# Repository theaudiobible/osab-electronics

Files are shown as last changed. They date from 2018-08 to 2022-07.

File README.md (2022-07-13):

## OSAB - the Open Source Audio Bible player
## [theaudiobible.org](http://theaudiobible.org/)
#### Copyright (C) 2011-2022 Theophilus

OSAB is a design for a portable audio Bible player released under the MIT Licence in the hope that it will be used by others worldwide to produce and distribute portable audio players that are specifically designed to share God's word with those who need to hear.

The intention is to share firmware, software, schematics, PCB layout and enclosure design along with instructions on how to put it all together.  The intention with the enclosure is that it be 3D-printable on a low cost FDM 3D printer, or mass-producible via injection moulding.

## osab-electronics
This is the repository for the EDA files for OSAB.

### Dependencies
- The schematic and PCB design tool is [KiCad](http://kicad.org/)
- [meshconv](https://www.patrickmin.com/meshconv/) is used to convert the VRML file to STL for use in OpenSCAD for the enclosure design.

### Generate STL file
To generate `osab.stl` for inclusion in the `osab-enclosure/osab.stl` soft link:
1. Open `osab.kicad_pcb` in KiCad Pcbnew.
2. Click `File` > `Export` > `VRML`.
3. Set these options:
   - `Coordinate origin options`: `User defined origin`
   - `User defined origin`:
      - `Units`: `mm`
      - `X`: `150`
      - `Y`: `100`
   - `VRML Units for Output Files`: `mm`
4. Click `OK`.  The output file should be `osab.wrl`.
5. Quit Pcbnew.
6. Download `meshconv` from https://www.patrickmin.com/meshconv/
7. Put meshconv somewhere in your PATH:
   `sudo chown root.root meshconv`
   `sudo chmod 755 meshconv`
   `sudo mv meshconv /usr/local/bin`
8. Convert the VRML file to STL as follows:
   `meshconv osab.wrl -c stl`
9. The output file `osab.stl` should be in the `osab-electronics` directory - there is a soft link from `osab-enclosure/osab.stl` to this file for inclusion in `osab-enclosure/osab-enclosure.scad`.

### Licence
This is open source hardware released under the MIT Licence - please see the LICENCE file in this directory.

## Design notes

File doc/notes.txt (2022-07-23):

Clone osab-electronics git repo
===============================

export OSAB_DIR=~/dev/osab
if [[ ! -d ${OSAB_DIR} ]]; then
  mkdir -p ${OSAB_DIR}
fi
cd ${OSAB_DIR}
if [[ ! -d osab-electronics ]]; then
  git clone https://github.com/audiobibleplayer/osab-electronics
fi
cd osab-electronics
git pull

External symbol + footprint + 3D libraries
==========================================

VS1000
------
library/vs10xx.lib is from http://www.kicadlib.org/modules/vs10xx.lib.zip

curl -o ${OSAB_DIR}/osab-electronics/libraries/symbols/vs10xx.lib https://raw.githubusercontent.com/karawin/Ka-Radio/master/Hardware/KiCAD/Main/vs10xx.lib

TF-01A
------
Download LIB_TF-01A.zip from https://componentsearchengine.com/ga/model.php?partID=2371673
unzip LIB_TF-01A.zip
cp -av TF-01A/3D/* ${OSAB_DIR}/osab-electronics/3D/
cp -av TF-01A/KiCad/TF01A.kicad_mod ${OSAB_DIR}/osab-electronics/libraries/footprints/samacsys.pretty/
cp -av TF-01A/KiCad/TF-01A.lib ${OSAB_DIR}/osab-electronics/libraries/symbols/

TYPE-C-31-M-12
--------------
curl -o ${OSAB_DIR}/osab-electronics/3D/TYPE-C-31-M-12.step https://raw.githubusercontent.com/ai03-2725/Type-C.pretty/master/HRO%20%20TYPE-C-31-M-12.step

XKB5858-Z-F
-----------
Download the STEP AP242 model from https://traceparts.com/ and place xkb5858-z-f.stp in ${OSAB_DIR}/osab-electronics/3D/

Kicad 5 setup in Linux
======================

Initial Setup
-------------

If upgrading from Kicad v4, assuming that you do not want to use v4 any more, then backup and remove ~/.config/kicad.

Clone official KiCad libraries into ~/dev/kicad.libs/OfficialKiCadLibrary from:
https://github.com/KiCad/kicad-symbols
https://github.com/KiCad/kicad-footprints
https://github.com/KiCad/kicad-packages3d

Run KiCad 5 and change the default global libraries to point to these closed official libraries.  Go to:
Preferences > Configure Paths
and set as follows (substitute 'user' for your user ID):

KICAD_SYMBOL_DIR   /home/user/dev/kicad.libs/OfficialKiCadLibrary/kicad-symbols
KICAD_TEMPLATE_DIR /home/user/dev/kicad.libs/OfficialKiCadLibrary/kicad-templates
KISYS3DMOD         /home/user/dev/kicad.libs/OfficialKiCadLibrary/kicad-packages3d
KISYSMOD           /home/user/dev/kicad.libs/OfficialKiCadLibrary/kicad-footprints

Create a dummy project so that you can set up the library tables for symbols and footprints - sym-lib-table and fp-lib-table:
File > New > Project
(select a temp path and file name)

Open the Schematic layout editor. A dialog titled 'Configure Global Symbol Library Table' will pop up.  Select the default:
Copy default global symbol library table (recommended)
and click OK.  This will create the file:
~/.config/kicad/sym-lib-table

Close Eeschema.

Open the PCB layout editor (Pcbnew). A dialog will pop up saying that you have run Pcbnew for the first time - click OK.  The Footprint library table should now exist at:
~/.config/kicad/fp-lib-table

Another dialog will pop up offering to enable graphics acceleration - it's generally best to enable this.

Close Pcbnew.

OSAB-specific setup
-------------------

Open the OSAB project in KiCad:
File > Open Project
Browse to osab/osab-electronics and open osab.pro.

Open osab.sch.

In Eeschema, go to:
Preferences > Manage Symbol Libraries...
Select the 'Project Specific Libraries' tab.
Click 'Add existing library to table' and browse to osab/osab-electronics/libraries/symbols and select osab.lib
Click 'Add existing library to table' and browse to osab/osab-electronics/libraries/symbols and select vs10xx.lib
Click 'Add existing library to table' and browse to osab/osab-electronics/libraries/symbols and select TF-01A.lib
Click OK to close the Symbol Libraries page.

In Footprint Editor, go to:
Preferences > Manage Footprint Libraries...
Select the 'Project Specific Libraries' tab.
Click 'Add existing library to table' and browse to osab/osab-electronics/libraries/footprints and select osab.pretty
 - for 'Description', add "OSAB footprint library"
Click 'Add existing library to table' and browse to osab/osab-electronics/libraries/footprints and select samacsys.pretty
 - for 'Description', add "SamacSys footprint library"
Click OK to close the Footprint Libraries page.

In Footprint Editor, go to:
Preferences > Configure Paths...
Under '3D Search Paths', click + and enter the following details:
Alias: KIPRJ3DMOD
Path: /home/user/dev/osab/osab-electronics/3D  (substitute 'user' appropriately)
Description: Project-specific 3D models
Click OK to close the Configure Paths page.

In Footprint Editor, go to:
Navigate to samacsys > TF01A
Double-click TF01A
Click Footprint properties
Select 3D Settings tab
Delete the existing 3D Model (click trash-can icon)
Click the + icon and add the following: ${KIPRJMOD}/3D/TF-01A.stp
Click OK

Save changes

Customising Footprints
======================
Change pin widths of TCS7191 from 0.5 mm to 0.4 mm to pass DRC.
Move X coordinate of pin MP1 of TF-01A from -7.34 mm to -7.44 mm to pass DRC.

Board Setup
===========
In Pcbnew, go to File > Board Setup... > Design Rules:
Allow blind/buried vias: uncheck
Allow micro vias (uVias) : uncheck
Require courtyard definitions in footprints: uncheck
Prohibit overlapping courtyards: check
Minimum track width: 0.2 mm
Minimum via diameter: 0.4 mm
Minimum via drill: 0.3 mm
Minimum uVia diameter: 0.2 mm
Minimum uVia drill: 0.1 mm
Minimum hole to hole: 0.25 mm

Design Rules > Net Classes:
Name    Clearance   Track Width   Via Size  Via Drill   uVia Size   uVia Drill  dPair Width   dPair Gap
Default 0.2 mm      0.25 mm       0.8 mm    0.4 mm      0.3 mm      0.1 mm      0.2 mm        0.25 mm
Power   0.2 mm      0.40 mm       0.8 mm    0.4 mm      0.3 mm      0.1 mm      0.2 mm        0.25 mm

Net Class Memberships (other than Default)
Net       Net Class
AVDD      Power
GND       Power
GNDA      Power
VCC       Power
VDD       Power

Howtos
======
To add new symbol fields: Preferences > Preferences > Eeschema > Field Name Templates > +

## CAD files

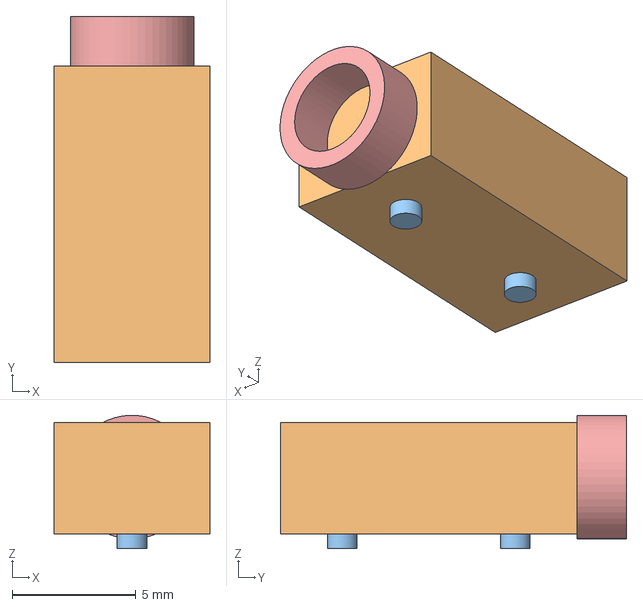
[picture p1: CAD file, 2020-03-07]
3D/PJ-3420.step
6.30 x 14.0 x 5.40 mm

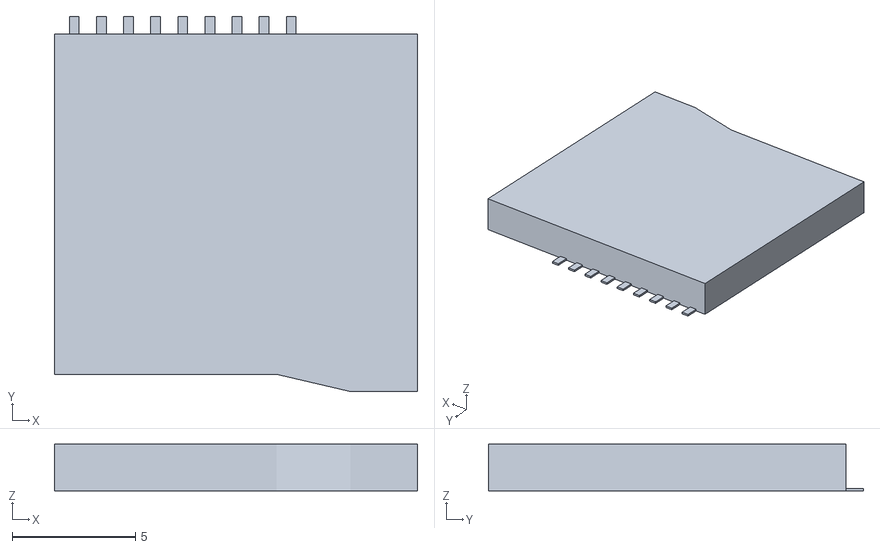
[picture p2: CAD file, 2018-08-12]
3D/Memory_Card_microSD_KNF1110X-AXX082.stl
14.7 x 15.2 x 1.90

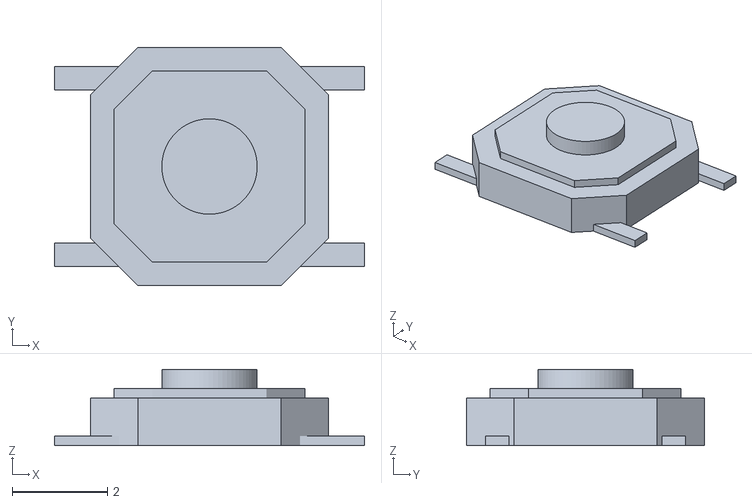
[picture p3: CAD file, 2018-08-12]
3D/pushbutton_5x5H1.stl
6.50 x 5.00 x 1.60

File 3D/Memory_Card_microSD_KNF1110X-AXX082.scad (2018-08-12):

/*
 * Memory_Card_microSD_KNF1110X-AXX082.scad - 3D component for Kicad
 * 
 * Copyright (C) 2014 Theophilus
 *
 * osab
 *
 * License: Matthew 10:8b - "freely ye have received, freely give."
 *
 * Use this information at your own risk.
 *
 */

// begin pin

// end pin
module pin() {
	cube([0.4,0.71,0.1]);
}

linear_extrude(height = 1.9)
polygon(points = [[0,0], [0,13.80], [14.72,13.80], [14.72,-0.7], [12.00,-0.7], [9.00,0.00]]);

start = 0.6;
translate([start,13.80,0]) pin();
translate([start+1*1.1,13.80,0]) pin();
translate([start+2*1.1,13.80,0]) pin();
translate([start+3*1.1,13.80,0]) pin();
translate([start+4*1.1,13.80,0]) pin();
translate([start+5*1.1,13.80,0]) pin();
translate([start+6*1.1,13.80,0]) pin();
translate([start+7*1.1,13.80,0]) pin();
translate([start+8*1.1,13.80,0]) pin();

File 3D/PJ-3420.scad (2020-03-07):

/*
 * PJ-3420.scad - Stereo 3.5mm audio socket
 * 
 * Copyright (C) 2015-2020 Theophilus
 *
 * osab
 *
 * License: Matthew 10:8b - "freely ye have received, freely give."
 *
 * Use this information at your own risk.
 *
 */

$fa=0.1; // default minimum facet angle is now 0.1
$fs=0.1; // default minimum facet size is now 0.1 mm

cube([6.3,12,4.5],center=true);
translate([0,7,0.05]) rotate([90,0,0]) difference() {
	cylinder(h=2,d=5,center=true);
	cylinder(h=2.1,d=3.6,center=true);
}

translate([0,3.5,-2.55]) cylinder(h=0.6,d=1.2,center=true);
translate([0,-3.5,-2.55]) cylinder(h=0.6,d=1.2,center=true);

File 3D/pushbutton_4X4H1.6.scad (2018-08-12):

/*
 * 4x4H1.6.scad - 3D Pushbutton Switch for Kicad
 * 
 * Copyright (C) 2015 Theophilus
 *
 * osab
 *
 * License: Matthew 10:8b - "freely ye have received, freely give."
 *
 * Use this information at your own risk.
 *
 */

$fa=0.1; // default minimum facet angle is now 0.1
$fs=0.1; // default minimum facet size is now 0.1 mm

module pin() {
	cube([1.5,0.5,0.2]);
}

linear_extrude(height=1)
polygon([[0,1],[1,0],[4,0],[5,1],[5,4],[4,5],[1,5],[0,4]]);

translate([0.5,0.5,1])
linear_extrude(height=0.2)
polygon([[0,4/5*1],[4/5*1,0],[4/5*4,0],[4/5*5,4/5*1],[4/5*5,4/5*4],[4/5*4,4/5*5],[4/5*1,4/5*5],[0,4/5*4]]);

translate([2.5,2.5,1.2])
cylinder(h=0.4, d=2);

translate([-0.75,0.4,0])
pin();

translate([-0.75,4.1,0])
pin();

translate([4.25,0.4,0])
pin();

translate([4.25,4.1,0])
pin();

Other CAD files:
3D/PJ3106.scad
3D/pushbutton_5x5H1.6.scad

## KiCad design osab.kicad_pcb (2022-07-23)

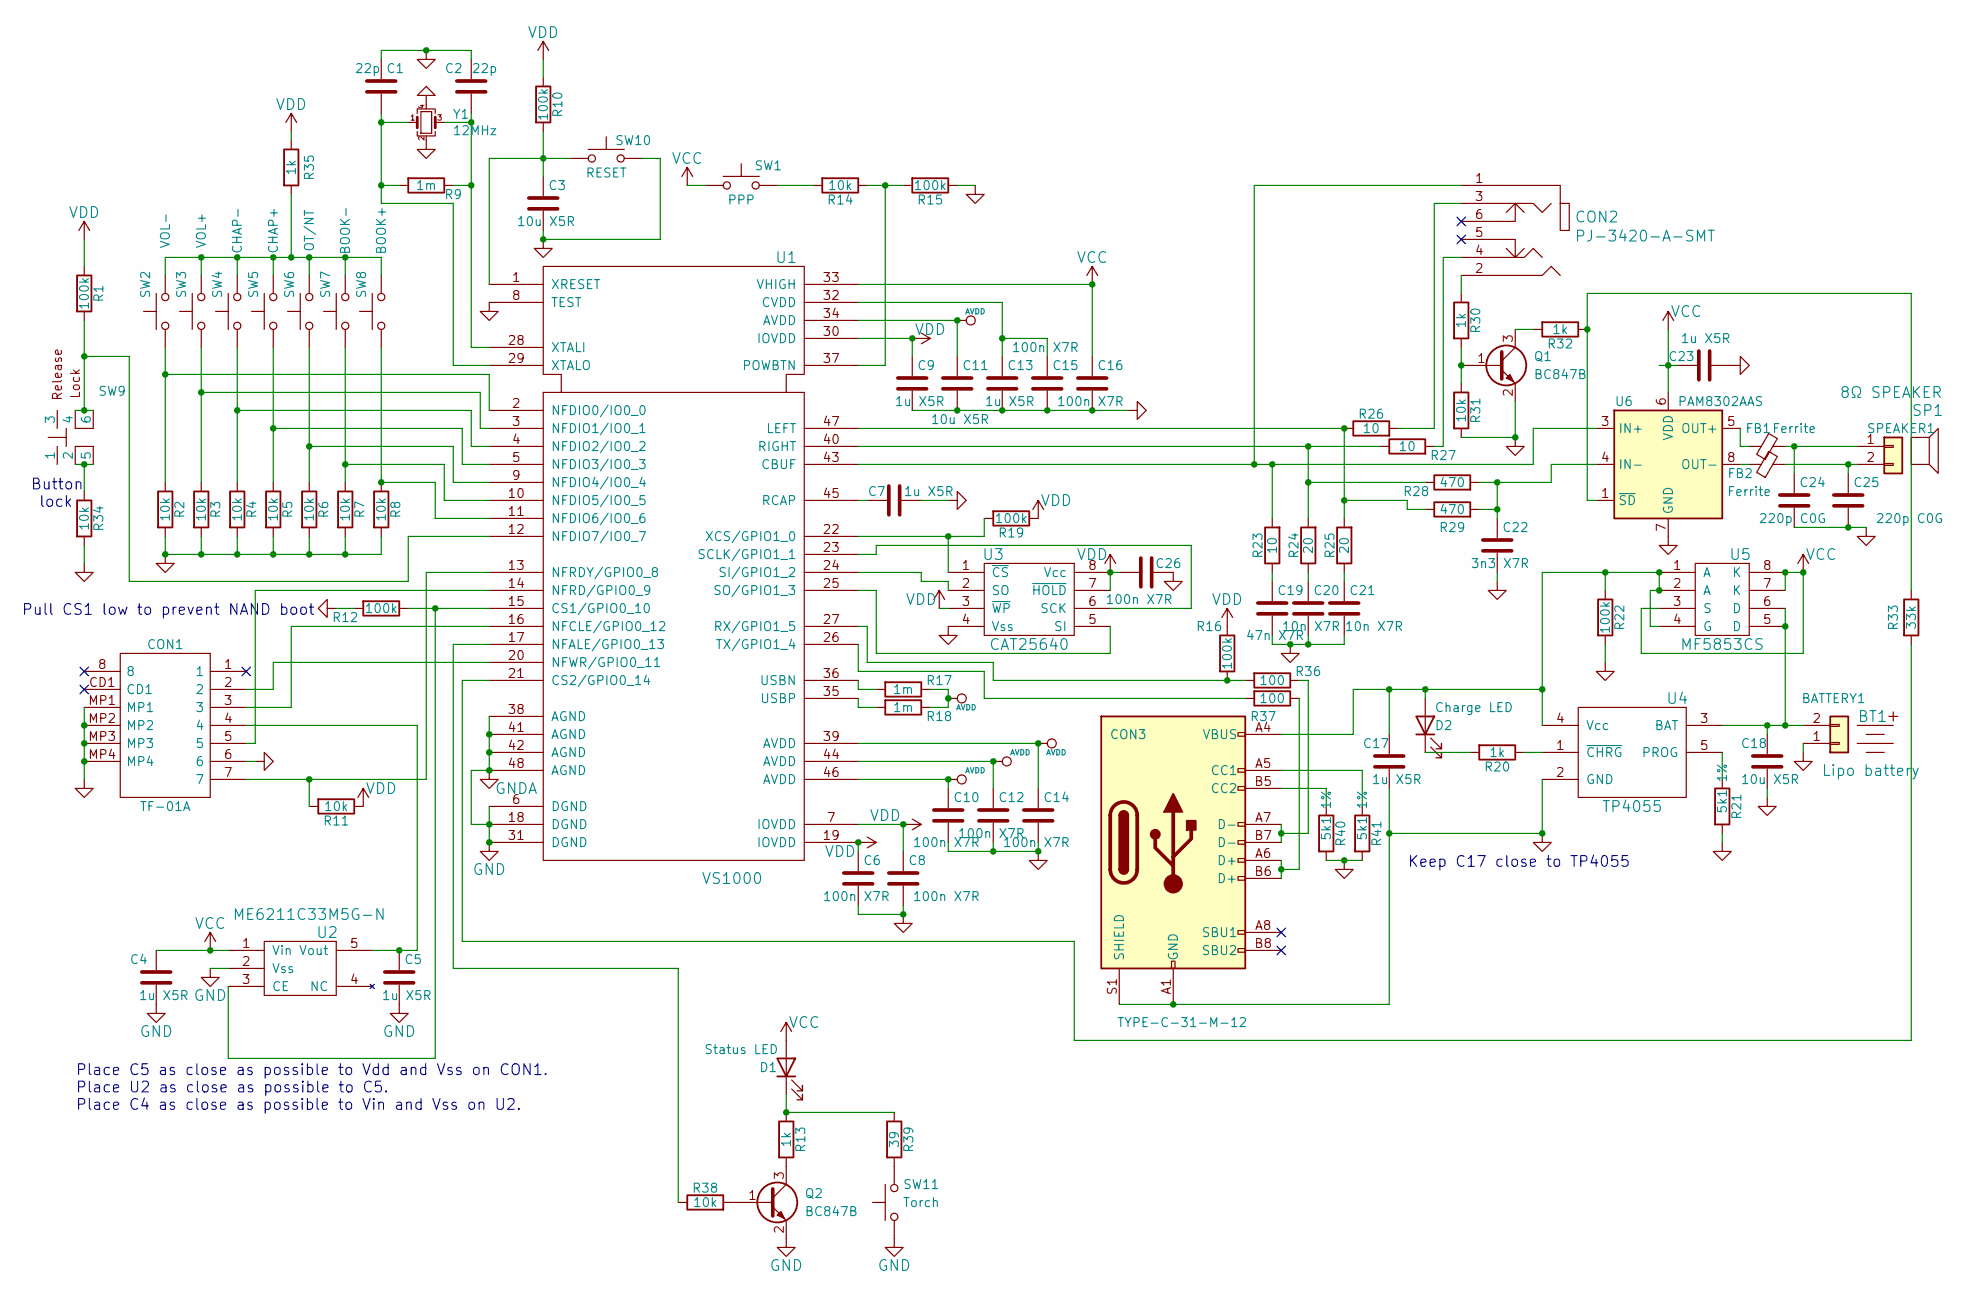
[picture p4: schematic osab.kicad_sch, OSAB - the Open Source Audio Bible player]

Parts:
BATTERY1: Conn_01x02; JST_PH_S2B-PH-SM4-TB_1x02-1MP_P2.00mm_Horizontal; MPN KH-A2001WF-02A; LCSC C2688784
BT1: Lipo battery; NULL; MPN BZ 602030
C1, C2: 22p; C_0603_1608Metric; MPN CL10C220JB8NNNC; LCSC C1653
C3, C11, C18: 10u X5R; C_0603_1608Metric; MPN CL10A106KP8NNNC; LCSC C19702
C4, C5, C7, C9, C13, C17, C23: 1u X5R; C_0603_1608Metric; MPN CL10A105KB8NNNC; LCSC C15849
C6, C8, C10, C12, C14, C15, C16, C26: 100n X7R; C_0603_1608Metric; MPN CL10B104KB8NNNC; LCSC C1591
C19: 47n X7R; C_0603_1608Metric; MPN CL10B473KB8NNNC; LCSC C1622
C20, C21: 10n X7R; C_0603_1608Metric; MPN CL10B103KB8NNNC; LCSC C1589
C22: 3n3 X7R; C_0603_1608Metric; MPN CL10B332KB8NNNC; LCSC C1613
C24, C25: 220p C0G; C_0603_1608Metric; MPN CL10C221JB8NNNC; LCSC C27675
CON1: TF-01A; TF01A; Manufacturer_Part_Number TF-01A; LCSC C91145
CON2: PJ-3420-A-SMT; MPN PJ-3420-A-SMT; LCSC C319102
CON3: TYPE-C-31-M-12; USB_C_Receptacle_HRO_TYPE-C-31-M-12; MPN TYPE-C-31-M-12; LCSC C165948
D1: Status LED; 0805-LED; MPN MHS171WDT-C2; LCSC C693902
D2: Charge LED; 0602-LED; MPN LTST-S270KRKT; LCSC C125114
FB1, FB2: Ferrite; R_0603_1608Metric; MPN MMZ1608Y152BTA00; LCSC C275454
Q1, Q2: BC847B; SOT-23; MPN BC847BLT1G; LCSC C94393
R1, R10, R12, R15, R16, R19, R22: 100k; R_0603_1608Metric; MPN ARG03FTC1003; LCSC C217682
R2, R3, R4, R5, R6, R7, R8, R11, R14, R31, R34, R38: 10k; R_0603_1608Metric; MPN ARG03FTC1002; LCSC C217687
R9, R17, R18: 1m; R_0603_1608Metric; MPN AR03FTC1004; LCSC C234360
R13, R20, R30, R32, R35: 1k; R_0603_1608Metric; MPN ARG03FTC1001; LCSC C217840
R21, R40, R41: 5k1 1%; R_0603_1608Metric; MPN ARG03FTC5101; LCSC C218090
R23, R26, R27: 10; R_0603_1608Metric; MPN ARG03FTC0100; LCSC C217691
R24, R25: 20; R_0603_1608Metric; MPN ARG03FTC0200; LCSC C217873
R28, R29: 470; R_0603_1608Metric; MPN ARG03FTC4700; LCSC C218042
R33: 33k; R_0603_1608Metric; MPN ARG03FTC3302; LCSC C217971
R36, R37: 100; R_0603_1608Metric; MPN ARG03FTC1000; LCSC C217683
R39: 39; R_0603_1608Metric; MPN 0603WAF390JT5E; LCSC C23154
SP1: 8Ω SPEAKER; NULL; MPN 28M03-8T-H52-L70; LCSC C391017
SPEAKER1: Conn_01x02; WAFER-125W-2P; MPN WAFER-125W-2P; LCSC C2840410
SW1: PPP; SW_SPST_TL3342; MPN K2-1187SQ-A4SW-06; LCSC C92584
SW2: VOL-; SW_SPST_TL3342; MPN K2-1187SQ-A4SW-06; LCSC C92584
SW3: VOL+; SW_SPST_TL3342; MPN K2-1187SQ-A4SW-06; LCSC C92584
SW4: CHAP-; SW_SPST_TL3342; MPN K2-1187SQ-A4SW-06; LCSC C92584
SW5: CHAP+; SW_SPST_TL3342; MPN K2-1187SQ-A4SW-06; LCSC C92584
SW6: OT/NT; SW_SPST_TL3342; MPN K2-1187SQ-A4SW-06; LCSC C92584
SW7: BOOK-; SW_SPST_TL3342; MPN K2-1187SQ-A4SW-06; LCSC C92584
SW8: BOOK+; SW_SPST_TL3342; MPN K2-1187SQ-A4SW-06; LCSC C92584
SW9: XKB5858-Z-F; MPN XKB5858-Z-F; LCSC C780036
SW10: RESET; SW_SPST_TL3342; MPN K2-1187SQ-A4SW-06; LCSC C92584
SW11: Torch; SW_SPST_TL3342; MPN K2-1187SQ-A4SW-06; LCSC C92584
U1: VS1000; LQFP-48_7x7mm_P0.5mm; MPN VS1000D-L; LCSC C486305
U2: ME6211C33M5G-N; SOT-23-5; MPN ME6211C33M5G-N; LCSC C82942
U3: CAT25640; SOIC-8_3.9x4.9mm_P1.27mm; MPN CAT25640VI-GT3; LCSC C153776
U4: TP4055; SOT-23-5; MPN TP4055; LCSC C28441
U5: MF5853CS; DFN8-2x3-0.65pitch; MPN MF5853CS; LCSC C375698
U6: PAM8302AAS; MSOP-8_3x3mm_P0.65mm; MPN PAM8302AASCR; LCSC C113367
Y1: 12MHz; Crystal_SMD_3225-4Pin_3.2x2.5mm; MPN X322512MSB4SI; LCSC C9002

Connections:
AVDD: C10.1, C11.1, C12.1, C14.1, R17.1, R18.1, U1.34 (AVDD), U1.39 (AVDD), U1.44 (AVDD), U1.46 (AVDD)
GND: BATTERY1.1, C1.1, C2.1, C3.2, C4.2, C5.2, C6.2, C7.1, C8.2, C9.2, C10.2, C11.2, C12.2, C13.2, C14.2, C15.2, C16.2, C17.2, C18.2, C19.2, C20.2, C21.2, C22.2, C23.2, C24.2, C25.2, C26.2, CON1.6, CON1.MP1, CON1.MP2, CON1.MP3, CON1.MP4, CON3.A1 (GND), CON3.A12 (GND), CON3.B1 (GND), CON3.B12 (GND), CON3.S1 (SHIELD), Q1.2 (E), Q2.2 (E), R2.2, R3.2, R4.2, R5.2, R6.2, R7.2, R8.2, R12.2, R15.1, R21.2, R22.2, R31.2, R34.2, R40.2, R41.2, SW10.1, SW11.1, U1.6 (DGND), U1.8 (TEST), U1.18 (DGND), U1.31 (DGND), U1.38 (AGND), U1.41 (AGND), U1.42 (AGND), U1.48 (AGND), U2.2 (Vss), U3.4 (Vss), U4.2 (GND), U6.7 (GND), Y1.2, Y1.4
unnamed: BATTERY1.2, C18.1, U4.3 (BAT), U5.5 (D), U5.6 (D)
unnamed: C1.2, R9.2, U1.29 (XTALO), Y1.1
unnamed: C2.2, R9.1, U1.28 (XTALI), Y1.3
unnamed: C3.1, R10.2, SW10.2, U1.1 (XRESET)
unnamed: C5.1, CON1.4, U2.5 (Vout)
unnamed: C7.2, U1.45 (RCAP)
unnamed: C13.1, C15.1, U1.32 (CVDD)
unnamed: C17.1, CON3.A4 (VBUS), CON3.A9 (VBUS), CON3.B4 (VBUS), CON3.B9 (VBUS), D2.2 (A), R22.1, U4.4 (Vcc), U5.1 (A), U5.2 (A), U5.4 (G)
unnamed: C19.1, R23.1
unnamed: C20.1, R24.1
unnamed: C21.1, R25.1
unnamed: C22.1, R28.2, R29.2, U6.4 (IN-)
unnamed: C24.1, FB1.2, SPEAKER1.1
unnamed: C25.1, FB2.2, SPEAKER1.2
unnamed: CON1.2, U1.20 (NFWR/GPIO0_11)
unnamed: CON1.3, U1.16 (NFCLE/GPIO0_12)
unnamed: CON1.5, U1.14 (NFRD/GPIO0_9)
unnamed: CON1.7, R11.2, U1.13 (NFRDY/GPIO0_8)
unnamed: CON2.1, R23.2, U1.43 (CBUF), U6.3 (IN+)
unnamed: CON2.2, R30.1
unnamed: CON2.3, R26.2
unnamed: CON2.4, R27.2
unnamed: CON3.A5 (CC1), R41.1
unnamed: CON3.A6 (D+), CON3.B6 (D+), R37.1
unnamed: CON3.A7 (D-), CON3.B7 (D-), R36.1
unnamed: CON3.B5 (CC2), R40.1
unnamed: D1.1 (K), R13.1, R39.1
unnamed: D2.1 (K), R20.2
unnamed: FB1.1, U6.5 (OUT+)
unnamed: FB2.1, U6.8 (OUT-)
unnamed: Q1.1 (B), R30.2, R31.1
unnamed: Q1.3 (C), R32.2
unnamed: Q2.1 (B), R38.2
unnamed: Q2.3 (C), R13.2
unnamed: R1.2, SW9.4, SW9.6, U1.12 (NFDIO7/IO0_7)
unnamed: R2.1, SW2.1, U1.2 (NFDIO0/IO0_0)
unnamed: R3.1, SW3.1, U1.3 (NFDIO1/IO0_1)
unnamed: R4.1, SW4.1, U1.4 (NFDIO2/IO0_2)
unnamed: R5.1, SW5.1, U1.5 (NFDIO3/IO0_3)
unnamed: R6.1, SW6.1, U1.9 (NFDIO4/IO0_4)
unnamed: R7.1, SW7.1, U1.10 (NFDIO5/IO0_5)
unnamed: R8.1, SW8.1, U1.11 (NFDIO6/IO0_6)
unnamed: R12.1, U1.15 (CS1/GPIO0_10), U2.3 (CE)
unnamed: R14.1, R15.2, U1.37 (POWBTN)
unnamed: R14.2, SW1.2
unnamed: R16.2, R36.2, U1.27 (RX/GPIO1_5)
unnamed: R17.2, U1.36 (USBN)
unnamed: R18.2, U1.35 (USBP)
unnamed: R19.2, U1.22 (XCS/GPIO1_0), U3.1 (~CS)
unnamed: R20.1, U4.1 (~CHRG)
unnamed: R21.1, U4.5 (PROG)
unnamed: R24.2, R27.1, R28.1, U1.40 (RIGHT)
unnamed: R25.2, R26.1, R29.1, U1.47 (LEFT)
unnamed: R32.1, R33.1, U6.1 (~SD)
unnamed: R33.2, U1.21 (CS2/GPIO0_14)
unnamed: R34.1, SW9.2, SW9.5
unnamed: R35.2, SW2.2, SW3.2, SW4.2, SW5.2, SW6.2, SW7.2, SW8.2
unnamed: R37.2, U1.26 (TX/GPIO1_4)
unnamed: R38.1, U1.17 (NFALE/GPIO0_13)
unnamed: R39.2, SW11.2
unnamed: U1.23 (SCLK/GPIO1_1), U3.6 (SCK)
unnamed: U1.24 (SI/GPIO1_2), U3.2 (SO)
unnamed: U1.25 (SO/GPIO1_3), U3.5 (SI)
VCC: C4.1, C16.1, C23.1, D1.2 (A), SW1.1, U1.33 (VHIGH), U2.1 (Vin), U5.3 (S), U5.7 (K), U5.8 (K), U6.6 (VDD)
VDD: C6.1, C8.1, C9.1, C26.1, R1.1, R10.1, R11.1, R16.1, R19.1, R35.1, U1.7 (IOVDD), U1.19 (IOVDD), U1.30 (IOVDD), U3.3 (~WP), U3.7 (~HOLD), U3.8 (Vcc)

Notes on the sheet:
Button lock
Pull CS1 low to prevent NAND boot
Place C5 as close as possible to Vdd and Vss on CON1. Place U2 as close as possible to C5. Place C4 as close as possible to Vin and Vss on U2.
Keep C17 close to TP4055

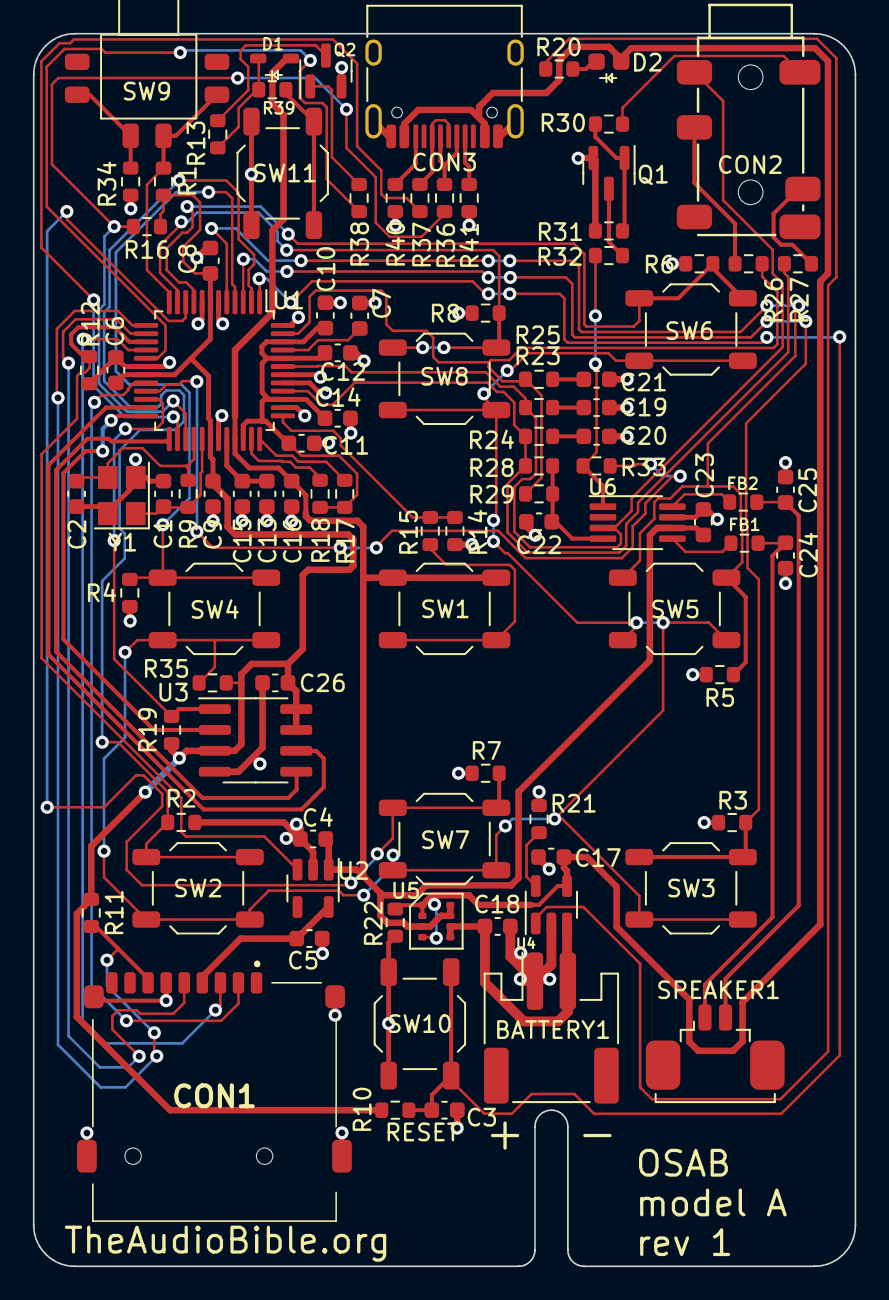
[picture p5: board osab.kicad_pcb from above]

Board: 2 copper layers, 50.0 x 75.0 mm, 98 parts (0 on the bottom side), 67 nets.

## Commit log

2018-08-12 Initial commit.
    [Memory_Card_microSD_KNF1110X-AXX082.scad, Memory_Card_microSD_KNF1110X-AXX082.stl, PJ3106.scad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]
2019-08-07 Changed all rescue symbols to their appropriate libraries
    Got rid of some superfluous? files
    Reorganised directory structure of libraries
    Kicad seems to have changed some refs
    Changed all X5R caps to X7R
    Updated board rev
    kicad-5: Changed footprints from 0603 to 0805 for hand soldering
    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
    [osab.sch]
2020-02-15 Comitting updates without zero ohm resistors to make a good point to branch multi-layer boards
    usb-c: Swapped microB for Korean-Hroparts TYPE-C-31-M-12
    usb-c: Multiple collapsed/consolidated changes
    usb-c: Added SamacSys model for TF-01A
    usb-c: A multitude of changes
    usb-c: Various changes
    usb-c: Various changes
    usb-c: Initial placement of all components on PCB
    usb-c: Extended board by 20mm
    usb-c: Further pcb layout changes
    usb-c: Changed headphone socket to PJ-3420-A-SMT
    usb-c: A multitude of changes
    usb-c: Rework around TF-01A
    usb-c: Working on pcb
    usb-c: Working on pcb
    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
    [osab.kicad_pcb, osab.sch, pushbutton_5x5H1.6.scad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]
2020-03-07 single-sided: Added 3D model for PJ-3420 3.5mm audio socket
    [PJ-3420.scad, PJ-3420.step, PJ3106.stl]
2020-08-02 Changed website in master branch
    [osab.sch]
2020-08-08 single-sided: Instructions to generate STL file for osab-enclosure
2021-11-08 Update README.md
    https://forum.kicad.info/t/warning-avoid-all-links-to-kicad-pcb-org-use-kicad-org/31521
2022-06-06 Production into master for OSAB model A rev 1 (#2)
    * production: C1,C2 -> 0603
    * production: C3,C11,C18 10u -> 0603
    * production: C4,C5,C7,C9,C13,C17,C23 1u -> 0603
    * production: Changed all 0805 cap footprints to 0603
    * production: 100n caps replaced with 0603 Samsung
    * production: Changed MPNs for earlier cap changes
    * production: Changed 1u from 10V to 50V
    * production: 3n3 to 0603
    * production: 47n to 0603
    * production: 10n to 0603
    * production: Changed all 0805 resistor footprints to 0603
    * production: Changed all 10k resistors to 0603
    * production: Changed all 100k resistors to 0603
    * production: Changed 1m resistor to 0603
    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
    [osab.kicad_pcb, osab.kicad_sch, osab.sch]
2022-07-13 production: Updated README to use meshconv (#3)
    [osab.kicad_pcb]
2022-07-22 prod-1: Added 3D model for USB-C
    [osab.kicad_pcb]
2022-07-23 prod-1: Added STEP model for XKB5858-Z-F button lock from traceparts.com
    [osab.kicad_pcb]

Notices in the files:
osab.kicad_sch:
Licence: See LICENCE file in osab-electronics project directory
